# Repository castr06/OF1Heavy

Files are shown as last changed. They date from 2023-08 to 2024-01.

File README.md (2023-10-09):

# OF1Heavy
OpenFrame1 Heavy box controller for Smash Bros. made with OpenSCAD!

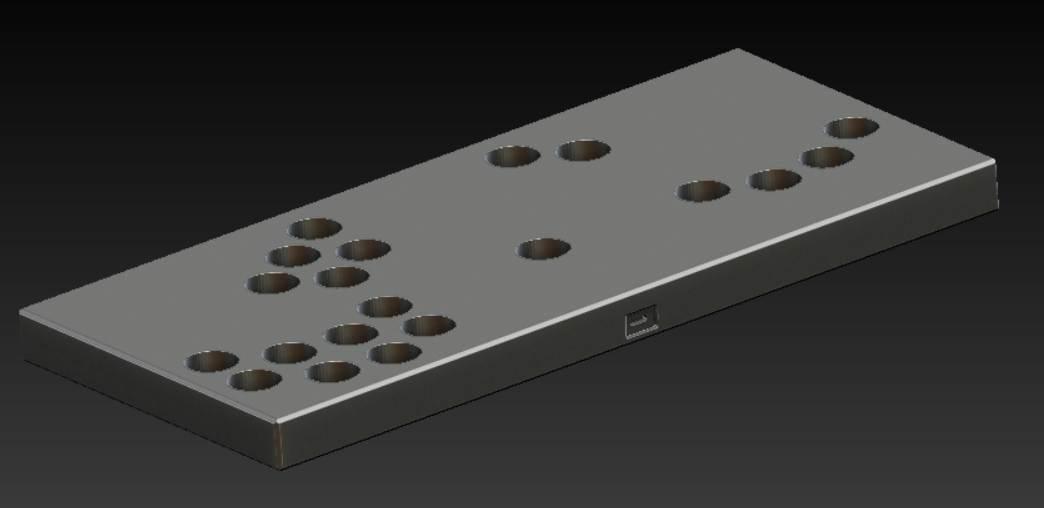
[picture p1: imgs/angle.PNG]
Angle

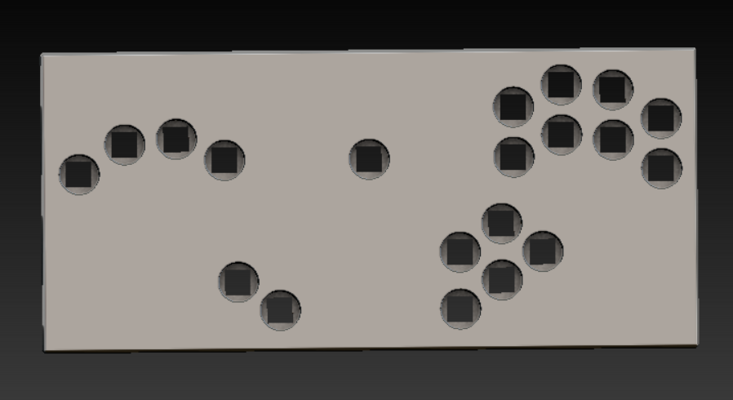
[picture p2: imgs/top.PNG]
Top

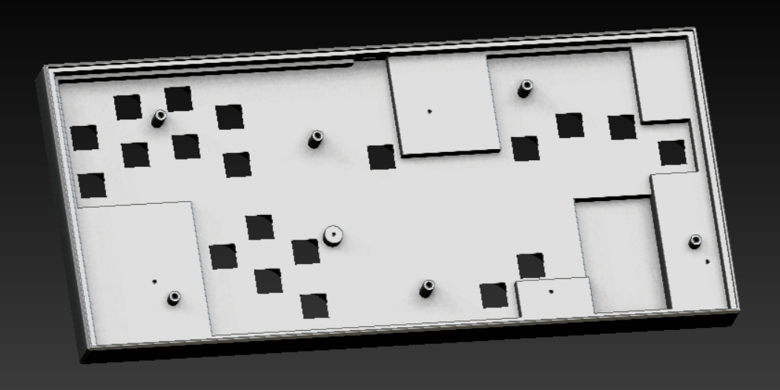
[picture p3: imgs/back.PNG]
Back

This is a custom OpenFrame1 case with a backplate, made with a built in thru-hole plate for the mx switches, to allow for making the box in only two pieces. This was made with CNC milling in mind. <br>
*images are renders dont mind the jagged lines*

# PCB/Board
This design is made for the [OpenFrame1 Board](https://github.com/GregTurbo/Open-Frame1) made by *GregTurbo*. <br>
You can also use the [Integrated OF1 Board](https://github.com/Armastardo/Integrated-OF1/tree/main) made by *Quark*.

# CNC Milling
The case should be made with 7/8in. stock.<br>
The backplate should be made with 1.6mm thick stock.

# Switches and Caps
Designed for standard/special profile Cherry MX style switches.<br>
For caps you can use any caps made to fit the Frame1 but an ideal open source solution is [NoCap](https://github.com/JonnyHaystack/NoCap) by *JohnnyHaystack*.

# Hardware
PCB Holes use M2.5 screws, backplate holes use M4 screws, and all holes in this build are made to fit 10mm screws if desired.<br>
<br>
**I recommend the hardware below:** <br>
*x5* of these style screws for the PCB: [M2.5 5mm Button Head Screw](https://www.mcmaster.com/92095A457/)<br>
*x6* of these style screws for a flush backplate fit: [M4 10mm Ultra-Low Profile Socket Head Screw](https://www.mcmaster.com/product/90358A006)<br>
<br>
If made in metal you will need to tap the holes, Most machinists can do this easily, just provide them the info on whichever screws you plan to use, and make sure those screws are the correct sizes (M2.5 and M4) and no deeper than 10mm from the beginning of the threading. <br>
If the screws you use for the backplate are not ultra-low profile or the head is taller than 1.3mm you **WILL NOT** have a flush fit with the case.<br>
As a note , the smaller holes that sit deeper in the case are the PCB screwholes and the ones that sit up higher and are slightly larger are the ones for the backplate.<br>
<br>
If made in plastic there is a chance you could just screw those screws in directly, but i would consider adding Heatset Inserts.<br>
If making a box out of plastic I would also highly consider checking out this [Full OpenFrame1](https://www.printables.com/model/394573-openframe1-full-case) if you have a larger printer or this [Glued OpenFrame1](https://www.printables.com/model/394572-openframe1-case-glued) if you have a smaller printer, both are made by *Davy*.<br>
Some other great projects are the [Rana Digital](https://github.com/rana-sylvatica/rana-digital) and the [OFOF1](https://github.com/rana-sylvatica/OFOF1) both by *Rana*.<br>
They are all much better suited to FDM printing and would use much less material.<br>
<br>
# Source Code
I have included the source code for this build, to build it in OpenSCAD you will need to download and set up this module:<br>
[Prism-Chamfer](https://github.com/hraftery/prism-chamfer) by *Hraftery*<br>
<br>

Made by yours truly with **<3**,
# YC<sup><sub>666</sub></sup>

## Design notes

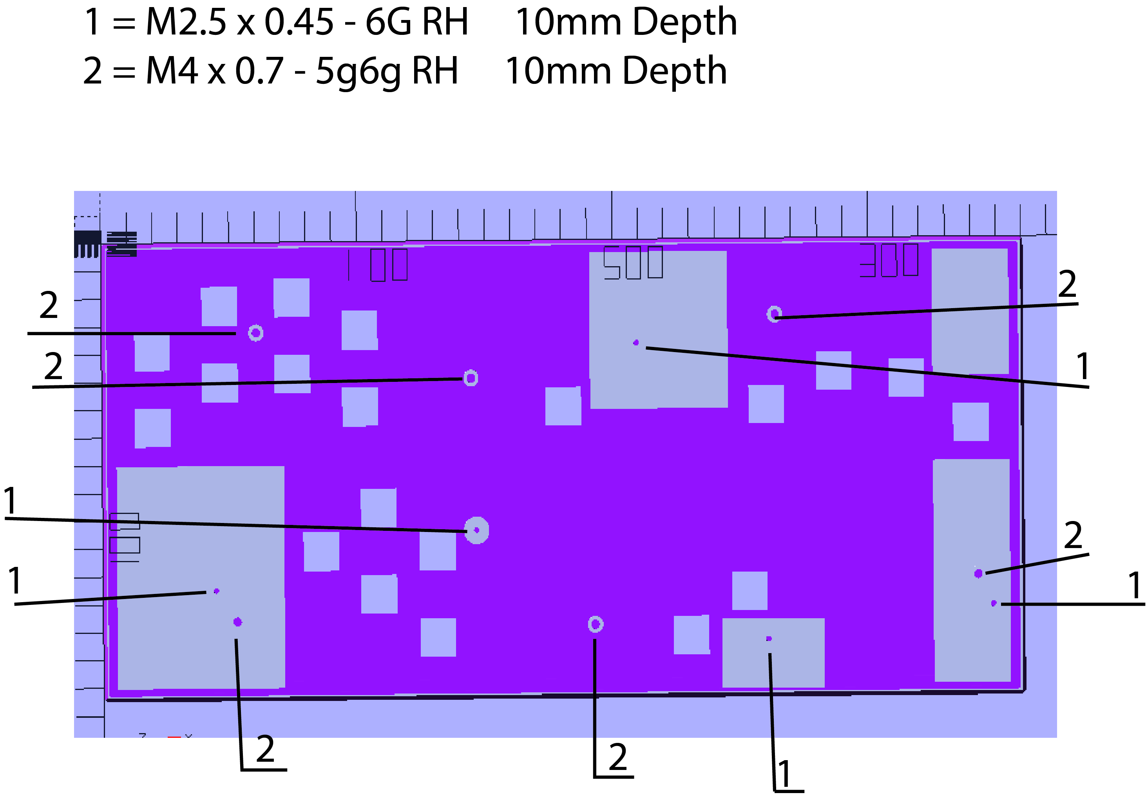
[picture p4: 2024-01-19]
threading technical drawing.jpg

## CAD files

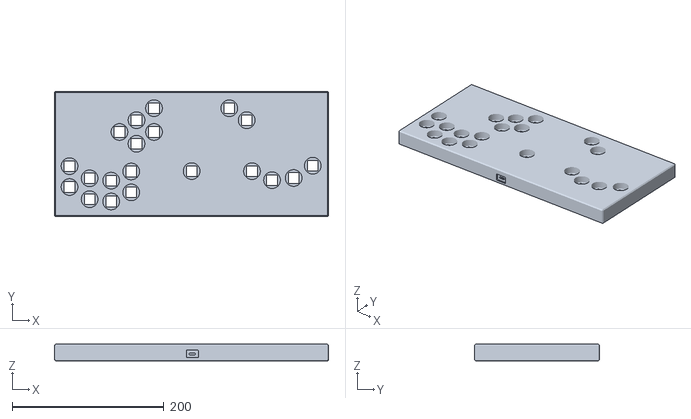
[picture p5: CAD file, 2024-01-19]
STL/OpenFrame1Heavy-v1.27.stl
360.7 x 165.0 x 22.2

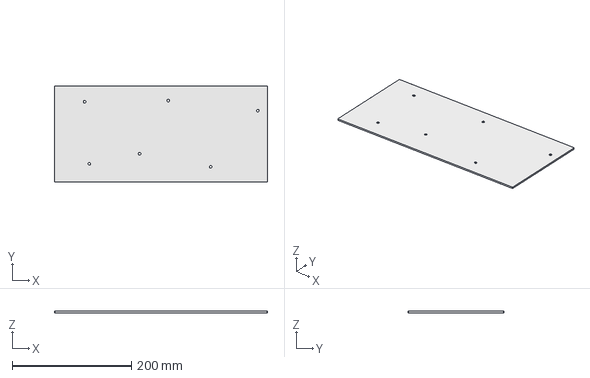
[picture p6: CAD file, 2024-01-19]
STEP/OpenFrame1Heavy-backplate-v1.27.step
356.6 x 160.9 x 2.60 mm

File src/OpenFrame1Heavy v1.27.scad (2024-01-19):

// OpenFrame1 Heavy by
/*
  //\ __ __                      ____          _         ___  
 |/_\|\ V / _   _ _ __   __ _   / ___|__ _ ___| |_ _ __ / _ \ 
  /_\|__ __| | | | '_ \ / _` | | |   / _` / __| __| '__| | | |
 / _ \__ __| |_| | | | | (_| | | |__| (_| \__ \ |_| |  | |_| |
/_/ \_\|_|  \__,_|_| |_|\__, |  \____\__,_|___/\__|_|   \___/ 
                        |___/                                 
*/
// Units are Unitless but most slicers will assume mm, so we will assume mm
//Backplate thickness should be 1.6mm with a rubber pad on the back
//first get the buttons mapped out.
//use jlcpcb to get measurements on the pcb board
//need to add extensions next to pico cutout so that they provide some extra places for th pcb to rest
//all hole and button measurements have 7mm on Y and 7mm on X added to them to account for case.

//174.5 usb c location with a 1.6mm height difference above the pcb resting point
//usb c board cutout dimensions 18.5 wide and 3mm deep and 2mm deep cutout in the front of the frame 
echo(version=version());
include <prism-chamfer.scad>;
$fn = 50; //Tells minkowski how many operations to perform in this case its 50*50
case = [360.7, 165, 22.225]; // Case Dimensions 22.225 tall is the height of 7/8in stock
deepest_cutout = [342.7, 151, 17.3]; //Internal Hollow Dimensions 5mm on x and y and 10mm for z if through hole for mx is too thick change z by 1mm thiner, 4mm differnce betwen pcb cutout so that pcb has 2mm all around to rest on 
pcb_cutout = [350, 157.5, 17.3]; //Internal Cut-out for holding pcb inbetween mx thru-hole which is a 5mm difference in height with 2mm for the backplate
backplate_cutout = [354.7, 159, 17.3];
pico_cutout =[43,68, 17.3];
button_radius = 10.32; //Button size is 20.64mm so adding just the slightest amount of space for tolerances
button_height = 9; //Button Height should be about 9mm
button_hole_height = 10; //Button hole Height should be about 10
button_hole_radius = 11; //Holes for the buttons should be around 22mm wide
mx_hole = 14; //Cherry MX thruhole standard is 14mm
usb_c = [5.8, 11, 2.6]; //width (8.4mm) is modified for cylinder dimensions to 5.8
thruhole_height = 13;
thruhole_radius = 3;
pcbhole_height = 7; 
pcbhole_radius = 5;
screwhole_height = 11;
screwhole_radius = 1.65;
pcb_screwhole_radius = 1.025;

module case(){
    difference(){
    polygon_points = [[0,0],[360.7,0],[360.7,165],[0,165]];
    h = 22.225;
    linear_extrude(height = h){ 
        polygon(polygon_points, convexity=2);
    }
    prism_chamfer_mask(polygon_points, start_edge=1, end_edge=4, height=h, side=1.5, corner_slope="deep");
    prism_chamfer_mask(polygon_points, start_edge=1, end_edge=4, height=0, side=1, corner_slope="deep");
    rotate([90,0,90]){
        prism_chamfer_mask(polygon_points, start_edge=1, end_edge=4, height=0, side=1.5, corner_slope="deep");
    }
    translate([0,165,0]){
        rotate([90,0,0]){
            prism_chamfer_mask(polygon_points, start_edge=1, end_edge=4, height=0, side=1.5, corner_slope="deep");
        }
    }
    translate([360.7,165,0]){
        rotate([90,0,0]){
            prism_chamfer_mask(polygon_points, start_edge=1, end_edge=4, height=0, side=1.5, corner_slope="deep");
        }
    }
     translate([360.7,0,0]){
        rotate([90,0,180]){
            prism_chamfer_mask(polygon_points, start_edge=1, end_edge=4, height=0, side=1.5, corner_slope="deep");
        }
    }
    }
}

/*Model Button
linear_extrude(height = button_height, center = true){
    circle(button_radius);
}
*/

/*Button Hole
linear_extrude(height = button_height, center = true){
    circle(button_hole_radius);
}
*/

//Model Assembly

//PCB Supports
//Support 1
difference(){
    translate([325,80.5,7.75]){
        color("white") cube([30,80,5]);
    }
    translate([348.3,132.3,7.75]){
        linear_extrude(height = screwhole_height){
            circle(pcb_screwhole_radius);
        }
    }
    translate([342.5,121.6,1.6]){
        linear_extrude(height = screwhole_height){
            circle(screwhole_radius);
        }
    }
}
//Support 2
translate([325,0,7.75]){
    cube([30,50,5]);
}
//Support 3
difference(){
    translate([191,1,7.75]){
        color("orange") cube([54,60,5]);
    }
    difference(){ 
        translate([196,16,10]){
            cube([11,25,10], center=true);
        }
    }
    translate([209.3,37.3,7.75]){
        linear_extrude(height = screwhole_height){
            circle(pcb_screwhole_radius);
        }
    }
}
//Support 4
difference(){
    translate([242,137,7.75]){
        color("red") cube([40,25,5]);
    }
    translate([260.3,144.3,7.75]){
      linear_extrude(height = screwhole_height){
            circle(pcb_screwhole_radius);
        }
    }
}
//Support 5
difference(){
    translate([1,80.5,7.75]){
        color("green") cube([70,80,5]);
    }
    translate([44.3,125.3,7.75]){
        linear_extrude(height = screwhole_height){
            circle(pcb_screwhole_radius);
        }
    }
    translate([52.5,136.5,1.6]){
        linear_extrude(height = screwhole_height){
            circle(screwhole_radius);
        }
    }
}

//PCB Mounting Holes
//Mount Hole 1 
translate([348.3,132.3,7.75]){
    difference(){
        linear_extrude(height = pcbhole_height){
            circle(pcbhole_radius);
        }
        linear_extrude(height = screwhole_height){
            circle(pcb_screwhole_radius);
        }
    }
}
//Mount Hole 2
translate([260.3,144.3,7.75]){
    difference(){
        linear_extrude(height = pcbhole_height){
            circle(pcbhole_radius);
        }
        linear_extrude(height = screwhole_height){
            circle(pcb_screwhole_radius);
        }
    }
}
//Mount Hole 3 
translate([209.3,37.3,7.75]){
    difference(){
        linear_extrude(height = pcbhole_height){
            circle(pcbhole_radius);
        }
        linear_extrude(height = screwhole_height){
            circle(pcb_screwhole_radius);
        }
    }
}
//Mount Hole 4 
translate([146.3,104.3,7.75]){
    difference(){
        linear_extrude(height = pcbhole_height){
            circle(pcbhole_radius);
        }
        linear_extrude(height = screwhole_height){
            circle(pcb_screwhole_radius);
        }
    }
}
//Mount Hole 5 
translate([44.3,125.3,7.75]){
    difference(){
        linear_extrude(height = pcbhole_height){
            circle(pcbhole_radius);
        }
        linear_extrude(height = screwhole_height){
            circle(pcb_screwhole_radius);
        }
    }
}

//Backplate mounting Thru-Holes
//Thru-hole 1
translate([342.5,121.6,1.6]){
    difference(){
        linear_extrude(height = thruhole_height){
            circle(thruhole_radius);
        }
        linear_extrude(height = screwhole_height){
            circle(screwhole_radius);
        }
    }
}
//Thru-hole 2
translate([263.5,27.5,1.6]){
    difference(){
        color("green") linear_extrude(height = thruhole_height){
            circle(thruhole_radius);
        }
        linear_extrude(height = screwhole_height){
            circle(screwhole_radius);
        }
    }
}
//Thru-hole 3
translate([192.5,138.5,1.6]){
    difference(){
        linear_extrude(height = thruhole_height){
            circle(thruhole_radius);
        }
        linear_extrude(height = screwhole_height){
            circle(screwhole_radius);
        }
    }
}
//Thru-hole 4    
translate([144.5,49.5,1.6]){
    difference(){
        linear_extrude(height = thruhole_height){
            circle(thruhole_radius);
        }
        linear_extrude(height = screwhole_height){
            circle(screwhole_radius);
        }
    }
}
//Thru-hole 5
translate([52.5,136.5,1.6]){
    difference(){
        linear_extrude(height = thruhole_height){
            circle(thruhole_radius);
        }
        linear_extrude(height = screwhole_height){
            circle(screwhole_radius);
        }
    }
}
//Thru-hole 6
translate([60.5,32.5,1.6]){
    difference(){
        linear_extrude(height = thruhole_height){
            circle(thruhole_radius);
        }
        linear_extrude(height = screwhole_height){
            circle(screwhole_radius);
        }
    }
}
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

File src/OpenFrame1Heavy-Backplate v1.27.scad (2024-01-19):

/*
  //\ __ __                      ____          _         ___  
 |/_\|\ V / _   _ _ __   __ _   / ___|__ _ ___| |_ _ __ / _ \ 
  /_\|__ __| | | | '_ \ / _` | | |   / _` / __| __| '__| | | |
 / _ \__ __| |_| | | | | (_| | | |__| (_| \__ \ |_| |  | |_| |
/_/ \_\|_|  \__,_|_| |_|\__, |  \____\__,_|___/\__|_|   \___/ 
                        |___/                                 
*/
$fn=50; //necessary for minkowski
backplate_cutout = [354.6, 158.9, 1.6]; //1.6mm thickness
screwhole_height = 11;
screwhole_radius = 2.25;
screw_flange_radius = 4;
//remove 3mm from each x and y on the openframe1heavy measurements
//backplate assembly
difference(){
   minkowski(){
        cube(backplate_cutout);
        cylinder(1, center=true);
    }
    //Backplate mounting Thru-Holes
        
    translate([-0.1,-0.1,0]){ 
        //Thru-hole 1
        translate([339.5,118.6,-2]){
            linear_extrude(height = screwhole_height){
                circle(screwhole_radius);
            }
        }
        //Thru-hole 2
        translate([260.5,24.5,-2]){
            linear_extrude(height = screwhole_height){
                circle(screwhole_radius);
            }
        }
        //Thru-hole 3
        translate([189.5,135.5,-2]){
            linear_extrude(height = screwhole_height){
                circle(screwhole_radius);
            }
        }
        //Thru-hole 4    
        translate([141.5,46.5,-2]){
            linear_extrude(height = screwhole_height){
                circle(screwhole_radius);
            }
        }

        //Thru-hole 5
        translate([49.5,133.5,-2]){
            linear_extrude(height = screwhole_height){
                circle(screwhole_radius);
            }
        }

        //Thru-hole 6
        translate([57.5,29.5,-2]){
            linear_extrude(height = screwhole_height){
                circle(screwhole_radius);
            }
        }
        //Backplate mounting Thru-Hole Flanges
        //Thru-hole Flange 1
        translate([339.5,118.6,-9.5]){
            linear_extrude(height = screwhole_height){
                circle(screw_flange_radius);
            }
        }
        //Thru-hole Flange 2
        translate([260.5,24.5,-9.5]){
            linear_extrude(height = screwhole_height){
                circle(screw_flange_radius);
            }
        }
        //Thru-hole Flange 3
        translate([189.5,135.5,-9.5]){
            linear_extrude(height = screwhole_height){
                circle(screw_flange_radius);
            }
        }
        //Thru-hole Flange 4    
        translate([141.5,46.5,-9.5]){
            linear_extrude(height = screwhole_height){
                circle(screw_flange_radius);
            }
        }

        //Thru-hole Flange 5
        translate([49.5,133.5,-9.5]){
            linear_extrude(height = screwhole_height){
                circle(screw_flange_radius);
            }
        }

        //Thru-hole Flange 6
        translate([57.5,29.5,-9.5]){
            linear_extrude(height = screwhole_height){
                circle(screw_flange_radius);
            }
        }
    }
}    

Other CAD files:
STEP/OpenFrame1Heavy-backplate-v1.0.step
STL/OpenFrame1Heavy-Backplate.stl
STL/OpenFrame1Heavy.stl
src/OpenFrame1Heavy-Backplate.scad
src/OpenFrame1Heavy.scad
STL/OpenFrame1Heavy-Backplate v1.27.stl

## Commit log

2023-08-16 Final Touches
    Noticed a small potential tolerance issue with USBC port and overmolding sizes for average USBC cables. So i increased the sizing to provide some more room and tolerance for cables that may have slightly large or offcenter overmolding.
    [OpenFrame1Heavy.stl]
2023-08-16 Tolerance fix
    Fixed the tolerance for the rim that the backplate rests on so that its much tighter and extends the lip that the backplate has from 0.5mm to a more grippable and manageable ~1mm, this will feel great when assembling and putting together.
    [OpenFrame1Heavy.stl]
2023-08-16 Final Update (Hopefully)
    Added the src code for the build, and also modified the frame to be 7/8in. by removing .175mm from the top, which will make milling and stock costs objectively cheaper.
    [OpenFrame1Heavy-Backplate.scad, OpenFrame1Heavy.scad, OpenFrame1Heavy.stl]
2023-08-16 FINAL UPDATE
    Made some aesthetic and milling tolerance changes. DONT ASK ME TO LOOK AT IT AGAIN <3
    [OpenFrame1Heavy.scad, OpenFrame1Heavy.stl]
2023-08-31 Upated Models
    Updated Models for Better Tolerances and fixed some intersection and face issues in the STEP files
    [OpenFrame1Heavy-Backplate.scad, OpenFrame1Heavy-Backplate.stl]
2024-01-19 Final Renditions
    Optimized backplate fit at ISO medium tolerance and for case as well. USBC tolerance fixes and section cut out for the quark openframe boards with integrated rpi, and included technical drawing for threadings to make ordering easier
    [OpenFrame1Heavy v1.27.scad, OpenFrame1Heavy-Backplate v1.27.scad, OpenFrame1Heavy-Backplate v1.27.stl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]
2024-02-10 Fixed Issues with step files
    hopefully
    [OpenFrame1Heavy-backplate-v1.0.step]
